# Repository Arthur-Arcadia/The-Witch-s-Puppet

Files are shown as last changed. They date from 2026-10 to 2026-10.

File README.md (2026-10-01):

# The Witch’s Puppet

A cooperative physical computing carnival game exploring haptic communication and information asymmetry.

## Project Documents

- [Project Case Study](the-witchs-puppet-project-case-study.md): concept, inspirations, gameplay, hardware, exhibition evaluation, and reflections.
- [Technical Description - Traps & Punishment](technical-description-traps-and-punishment.md): trap sensing, ESP32 communication, enclosure iterations, code excerpts, and prototype outcomes.
- [Watch the project demonstration](https://www.youtube.com/watch?v=2GjQerEt0JA)

## Image Assets

Keep the `assets/` directory alongside the Markdown files. Images use relative paths and retain the original files extracted from the Word documents.

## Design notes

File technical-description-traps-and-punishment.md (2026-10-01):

# Technical Description - Traps & Punishment

**Author:** Zirui Zhou

[Project case study](the-witchs-puppet-project-case-study.md)

## Project Context and My Role

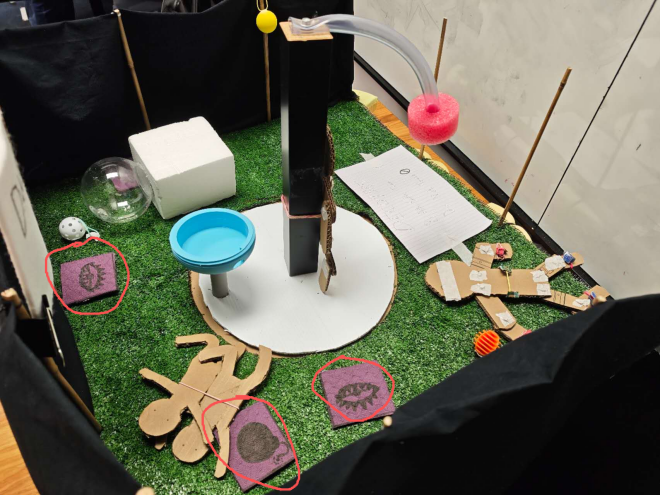
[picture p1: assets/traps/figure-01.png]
Game layout and trap placement


Our group’s project, initially called ‘Dungeon Escape’ and later named ‘The Witch’s Puppet’, where the witch tied in the middle have to control the puppet who is completely blind and deaf to pick up keys and put them into the groove in corresponding order. While the puppet move around, there will be traps that punish the witch if the puppet step onto it.

As the picture illustrated, I am responsible for traps and the punishment structure.

## Design Requirements and Initial Approach

As we expected from the beginning, the trap should be imperceptible, which means the puppet shouldn’t be aware when he/she stepped unto it, so the the witch will be continuously punished until the puppet move away.

SO my idea at first was to make a distance sensitive trap that detects the deformation of the stepping layer when the puppet step onto it. It will have a cover layer for the puppet to step on as well as for the sensor to detect the deformation. Then the problem comes to, how would I be able to hide all those sensors and circuit components below a structure that the puppet will not be noticed? It must be low and smooth enough compare to the normal ground to not let the puppet be noticed.

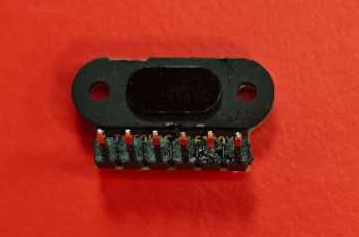
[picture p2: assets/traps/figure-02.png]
Time-of-Flight ranging sensor


This was the first difficulty I had encountered when I’m using the TOF050C, which is called the Time of Flight Laser Ranging Sensor Module.

This sensor sends out a single laser and detects the bouncing time to calculate the range of the object in front of it.

In order to let the player move smother and less annoyed by wires and cables, I decide to use ESP 32 as the board to send out signals remotely, so that a 5v battery is enough to power up a group of trap.

To establish a stable and reusable circuit, I used solder to attach extra footer onto the sensor as well as connecting cables. I also plan to add a LED strip into the system as an indicator for audiences and the witch to know which trap is triggered.

## Success Criteria

As long as the trap detection functions as expected, the puppet will not be awared whether the trap is triggered or not, and the witch and audiences will know which trap is triggered, then it is succeed.

## Initial Structure

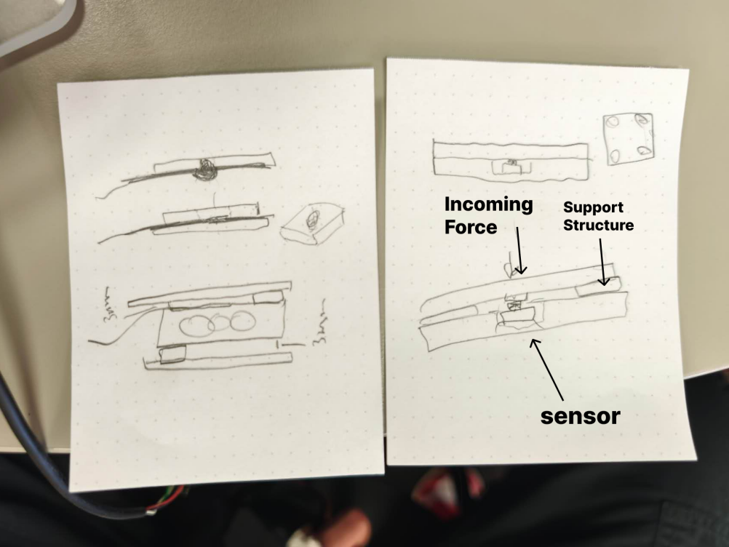
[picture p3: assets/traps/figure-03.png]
Initial trap sensing structure


The accompanying illustration shows the basic idea of how this trap is working, there will be support structure between the top and the bottom layer to allow the top layer to have deformation space. Then the sensor will collect the data. The accompanying circuit image illustrates the electronics; the initial 3D-printed structure is discussed separately.

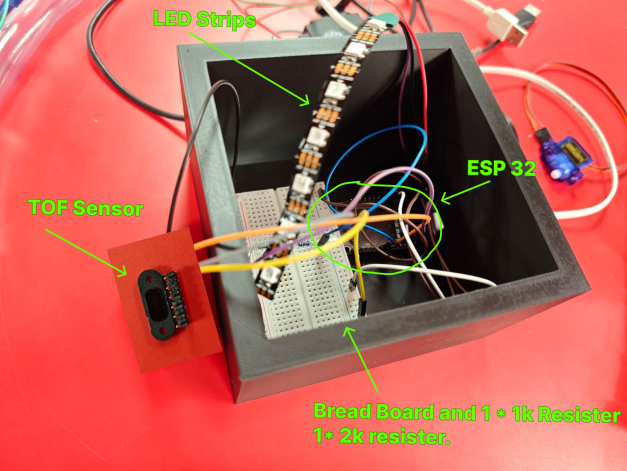
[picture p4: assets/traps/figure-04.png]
Initial trap circuit


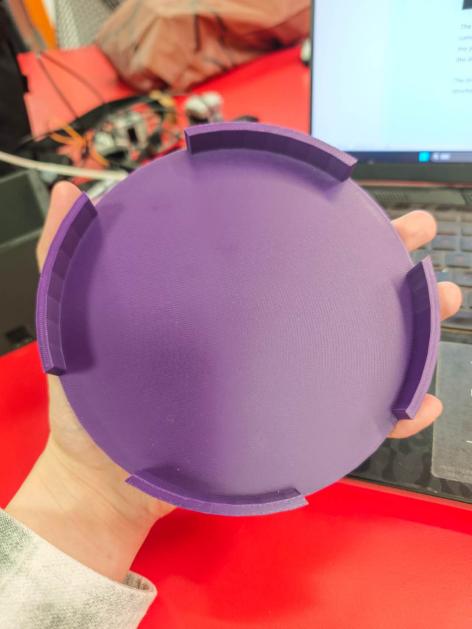
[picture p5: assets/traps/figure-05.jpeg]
Initial circular trap prototype


The circuit react smoothly, so I plan to build a 3D structure to contain the circuit structure. After communication with team mates, we believe the trap shouldn’t be too thick or too high, so that the puppet who can’t see will not be tripped over by the trap. It also have to be big enough to let the deformation happens obvious enough for the sensor to detect.

The initial 3D structure looks like the accompanying prototype, it’s a circle plate with four supporting structures and space to contain circuits. However, it did not fulfill it’s design purpose. It’s a bit too high for puppet to ignore the shape when step onto it, and too low at the same time to not damage the component after covering the circuit on the ground. I.e. if hide all components directly under this plate, the wire would be bent too much to transfer signals.

So this plan was abandoned, as well as the intention to let the puppet step onto the trap. Unless we can raise the ground of the 3\*3m field and place those traps at the same height, otherwise this stepping trick is difficult to be imperceptible.

## Iterations and Fabrication

Fortunately, there’s another sensor called ultrasonic distance sensor that detects wider area of distance compared to the TOF sensor, which means I can place it aside and detects whether the player’s feet is within the certain range.

The puppet no longer need to step onto the trap, it will be triggered as long as the player is closer enough to the trap. The new circuit structure was created, come alone with the 3D printed container. Version 1 looks like below:

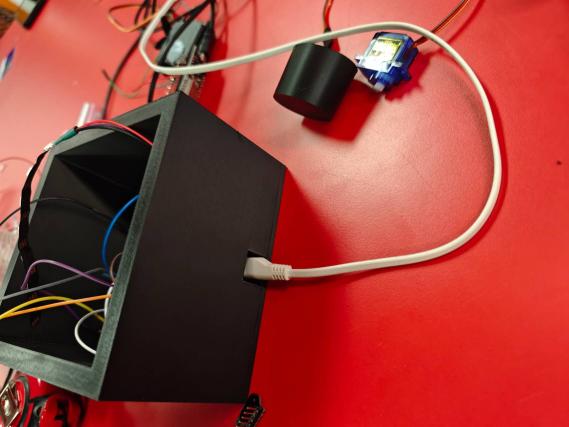
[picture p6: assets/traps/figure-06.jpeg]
Ultrasonic trap prototype


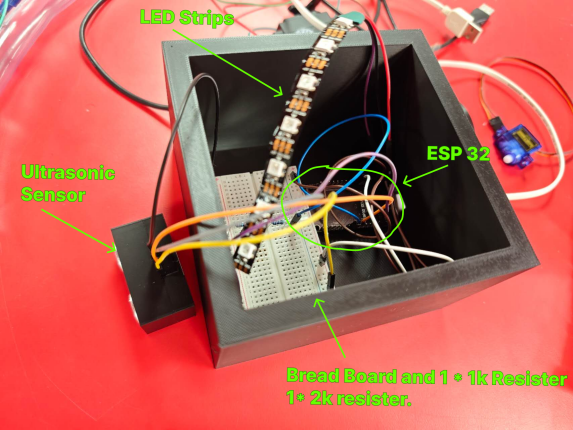
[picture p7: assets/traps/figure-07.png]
Ultrasonic trap circuit


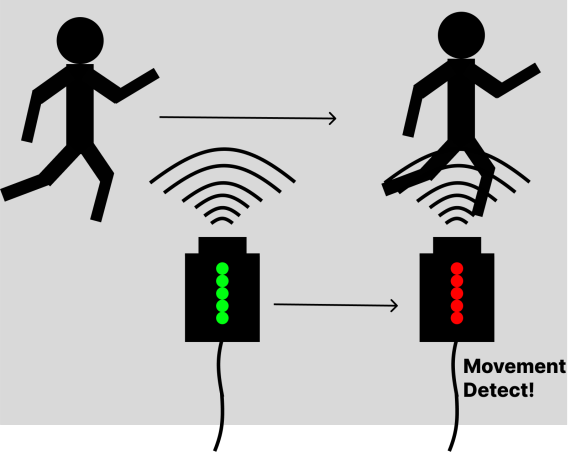
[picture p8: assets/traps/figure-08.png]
First enclosure design


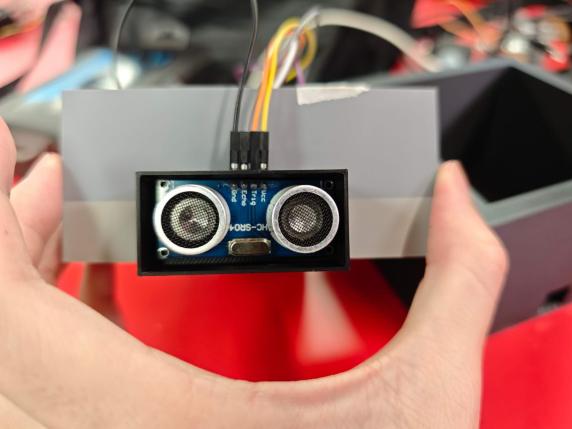
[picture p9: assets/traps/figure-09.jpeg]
Assembled trap enclosure


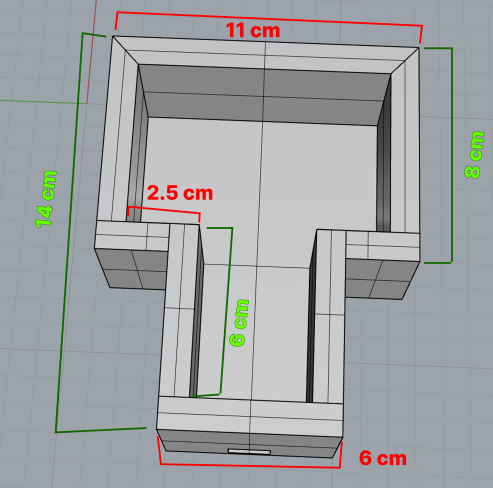
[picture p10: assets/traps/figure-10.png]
Revised enclosure with fitted component compartments


As the photo illustrated above, I have designed a container to put the circuit in, so that it will not be damaged easily if the player accidentally kicked or stepped onto it. However, the box for version 1 seems too large to safely contain all the components without worrying the displacement when experiencing shaking and rolling. So after measuring the specific length of each component, version 2 was designed as shown in the accompanying illustration. The wider area is for the bread board, and the thinner and longer area is for ESP 32 Board. Version 2 successfully limited the movement of each component and maintained the position of every cables.

## Microcontroller Selection and Wireless Communication

The purpose of the trap is to activate the ‘punishment machine’ hangs at the top of the witch, since these traps will be randomly located for each new round, cables and wires is the biggest limitation that might affect puppet’s movement. So our group decides to use remote communication, which comes to the ESP 32, the micro-controller integrated with Wi-Fi and Bluetooth communication.

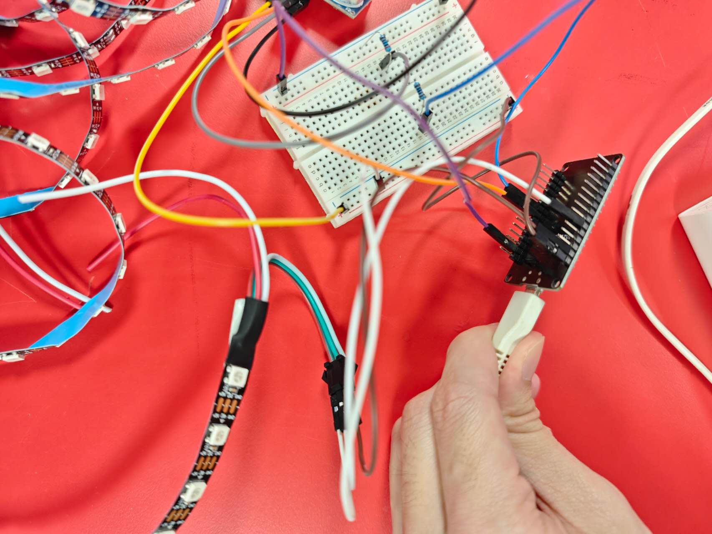
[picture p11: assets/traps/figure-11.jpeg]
ESP32 hardware


This micro-controller allows remote data transmission with 5v and 3.3v power outlet, and up to 30 pins (includes power) for components. However, the operating current is lower than Arduino UNO (about 500mA), so extra power supply is needed to drive components like motor.

Since the data is sent by the trap and received by the punishment system, 2 esp32 is needed to communicate between each other.

As the research and AI suggested, a communication method called ‘ESP NOW’ is highly recommended by sending the data through ESP32’s Wi-Fi module directly to another ESP32 with corresponding MAC address without using actual WLAN.

So the whole system was developed based on 2 separate codes, correspondingly responsible for sending and receiving. More specifically, the sending code receives data from ultrasonic distance sensor, and sends out through ESP-NOW, while triggers color changing of LED strip. On the other side, another ESP 32 receives the data and trigger the servo if the trap was triggered.

The following images show excerpts of the sending and receiving code.

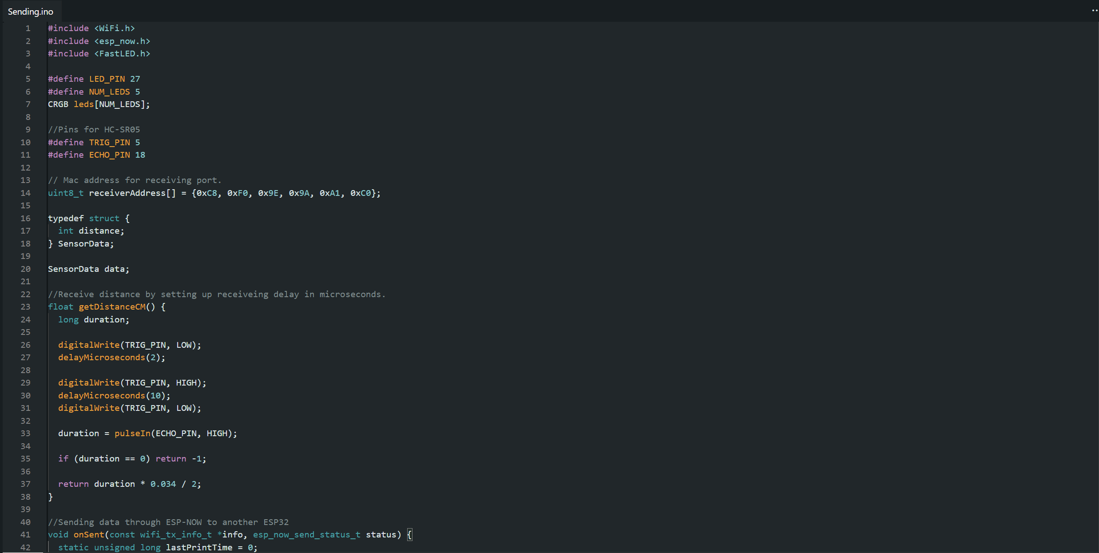
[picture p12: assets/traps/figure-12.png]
Sender code excerpt


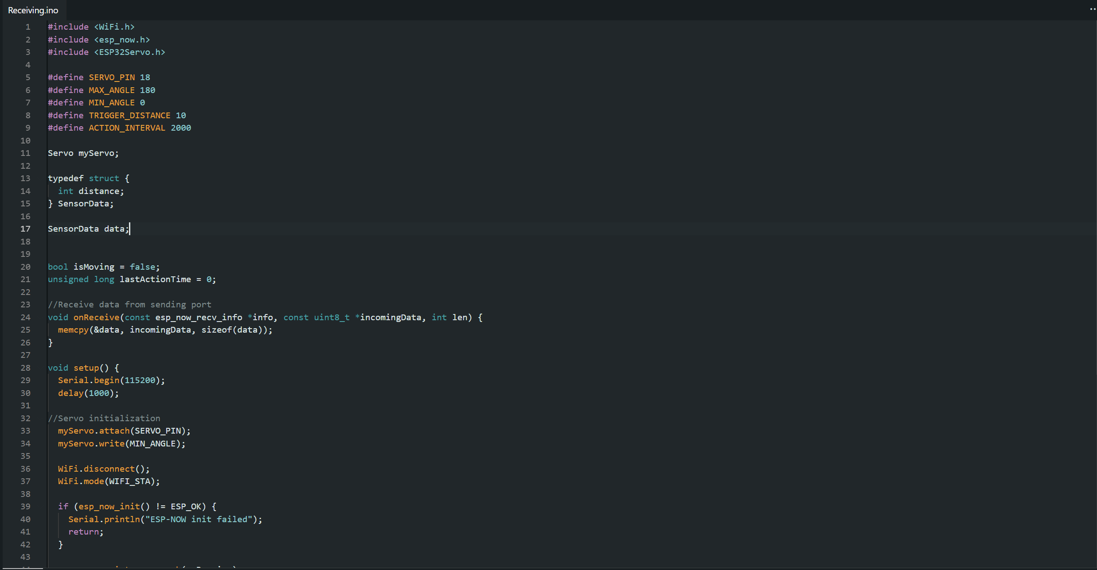
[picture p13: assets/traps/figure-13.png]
Receiver code excerpt


## Limitations and Next Iteration

Since this ‘pass through detecting’ trap is a bit large in volume, a kicking or treading could seriously damage and affect the current circuit, even under the protection of 3D printed shell. And a bread board is used with unsturdy cable connection for this ‘Tech Spike’. The next iteration will focus on reducing its volume and reinforce the stability of the circuit.

## Prototype Outcome

The answer is yes for the current period. The trap can be triggered accurately and rapidly, the delay of data transmission between two ESP32 is within acceptable range, so I believe my design has achieved its design purpose.

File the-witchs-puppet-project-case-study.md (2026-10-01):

# The Witch’s Puppet — Project Case Study

**Author:** Zirui Zhou  
**Institution:** University of Queensland

[Technical Description - Traps & Punishment](technical-description-traps-and-punishment.md) · [Project demonstration](https://www.youtube.com/watch?v=2GjQerEt0JA)

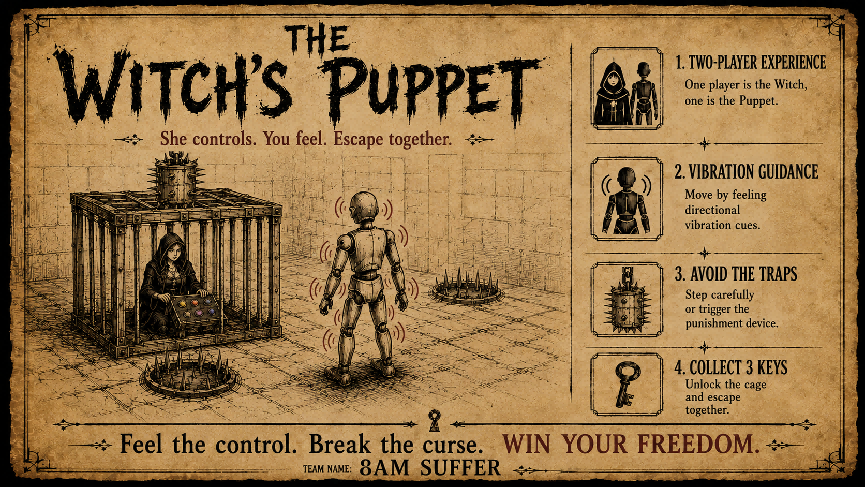
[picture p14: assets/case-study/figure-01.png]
The Witch’s Puppet project poster


*Figure 1: Poster for The Witch’s Puppet.*

## Project Overview

Traditional carnival games usually provide players with visual appeal, extreme emotional feedback, and a sense of achievement by using lights, sounds, and interactions. They test players’ strength, speed, accuracy, and reactions by setting up simple rules and different levels of challenges, bringing happiness and an unforgettable experience to both players and spectators. What will carnival games look like in the future?

This paper presents an interactive prototype project that explores a alternative theme to traditional competitive carnival games: cooperation. In this game, two players act separately as the witch and the puppet. The goal is simple: the witch has to control the movement of the puppet (who is blind and deaf) through a panel, and the puppet has to follow the commands to move around the field, collecting keys while avoiding traps.

This project shows our understanding of and attempts toward future carnival games. It will also show how this game creates cooperative experiences through restricted, asymmetrical communication, and physical interaction.

## Research Areas

- **Human-centered computing** → Interaction Design → Interaction design process and method

- **Hardware** → Sensor devices and platforms

## Keywords

Interaction Design, Carnival Games, Physical Interactive Experience, Haptic Communication, Remote Data Transmission through Electrical Components

## Introduction

From remote communication to virtual reality, the forms of interaction that humans can experience have been constantly changing with the development of technology. The same goes for carnival games. From the baseball toss, balls-in-the-bucket, and ring toss seen in old carnival photos [2], to Whac-A-Mole, Dance Dance Revolution, Laser Maze, and VR shooting games, the evolution of technology has enriched the ways users can interact with games. It can be expected that technology will play a larger role in future carnival games, creating more immersive and realistic experiences for players and offering developers more design opportunities and creative expressions.

Inspired by marionettes and dungeon escape rooms, Witch’s Puppet combines both puppet manipulation and escape elements to provide a unique experience for players. Similar to a marionette show, the witch needs to control the movement of the puppet, while the puppet has to avoid traps and collect keys hanging in random locations, ultimately saving the witch from the cage.

This project aims to explore the relationship between technology and interaction, as well as define a possible theme for future carnival games. Specifically, technology uniquely shapes the gameplay experience by challenging players to maintain remote communication within a restricted environment.

## Related Work and Inspirations

The inspiration for this project came from various aspects. The way of communication between the witch and the puppet imitates the manipulation of the traditional ‘Marionette’, where strings are attached all around the puppet’s body to enable sensitive movement control [4].

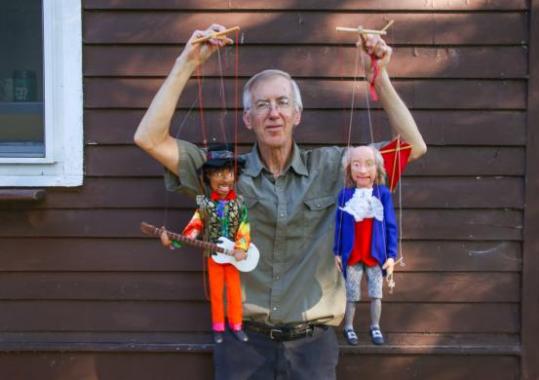
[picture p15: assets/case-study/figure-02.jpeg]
Marionette inspiration


*Figure 2: A puppeteer is showing his puppets*

Instead of using strings and ropes, this project integrates electronic components and wearable haptics to maintain communication between the witch and the puppet, solving both distance and stability problems for remote control. The concepts of the cage, traps, and the rescue mechanism came from the game ‘Dungeon Escape’, where the player needs to get keys while avoiding traps and monsters, ultimately escaping from the dungeon [1]. 

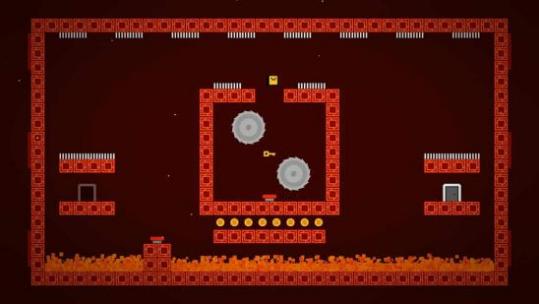
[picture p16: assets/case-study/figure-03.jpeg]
Dungeon Escape inspiration


*Figure 3: The game ‘Dungeon Escape’*

However, instead of punishing the puppet who triggers the trap, the punishment system—which is remotely connected to the traps—will punish the witch who controls the puppet. This means the witch has to bear the consequences for leading the puppet into a trap.

In addition, this game grounds the witch and deprives the puppet of sight and hearing, so that the witch can only give commands, and the puppet can only follow them without knowing the exact situation. This idea was extracted and combined from the games ‘It Takes Two’ and ‘Keep Talking and Nobody Explodes’.

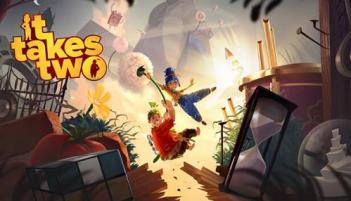
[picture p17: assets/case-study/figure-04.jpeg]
It Takes Two inspiration


*Figure 4: It Takes Two.*

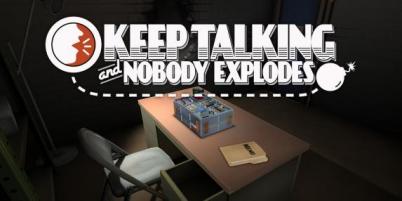
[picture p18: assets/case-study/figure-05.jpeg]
Keep Talking and Nobody Explodes inspiration


*Figure 5: Keep Talking and Nobody Explodes.*

While both games emphasize cooperation between players, ‘It Takes Two’ focuses more on collaboration to solve puzzles and difficulties together [5], whereas ‘Keep Talking...’ highlights the information asymmetry between players [3]. Therefore, Witch’s Puppet extracts the idea of ‘cooperation’ while maintaining ‘information asymmetry’ to form a completely different experience between the witch and the puppet.

## Design and Implementation

Considering the player experience and difficulty level, this game removes the time limit to ensure that every pair of players can finish the game. Players are allowed to have a conversation before the start of the game to discuss any strategy. With three keys in total, the puppet can only carry one key at a time until it is placed into the correct slot. While this game focuses mainly on communication and punishment, the gameplay flow is relatively simple.

1. Discuss strategy.
2. Test the vibration mappings.
3. Navigate the space and avoid traps.
4. Collect and place the keys.
5. Unlock the cage.

### Technical Detail

The core component of this project is the esp-32 Module, it ensures the remote communication while prevent the puppet from tripping over the circuits when moving around. 11 ESP-32 S3 Zero and 1 ESP-32 Devkit v1 were used for the final iteration, 4 on the traps, 1 on the punishment system, 1 for the controller, and 6 for the wearable set.

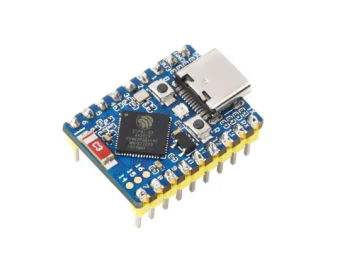
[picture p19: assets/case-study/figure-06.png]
ESP32 S3 Zero


*Figure 6: ESP32 S3 Zero.*

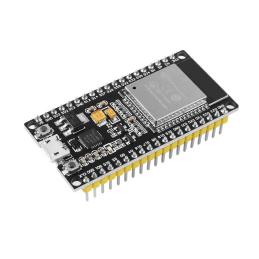
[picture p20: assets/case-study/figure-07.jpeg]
ESP32 Devkit V1


*Figure 7: ESP32 Devkit V1.*

Six 5V mini vibration motors are deployed on the wearable set, with each connected to an ESP-32 S3 Zero.

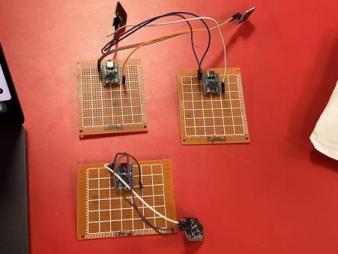
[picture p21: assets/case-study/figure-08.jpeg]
Wearable vibration motor and ESP32 assembly


*Figure 8: Vibration motor and ESP32 assembly.*

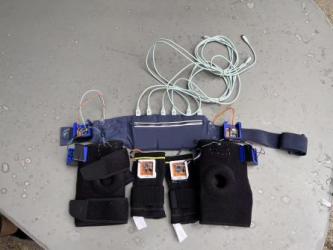
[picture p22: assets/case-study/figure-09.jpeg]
Complete wearable haptic system


*Figure 9: Complete wearable haptic system.*

The controller is composed of 6 buttons and 1 ESP-32, each button sends signals through a specific MAC address corresponding to the unique esp-32 attached to puppet’s body.

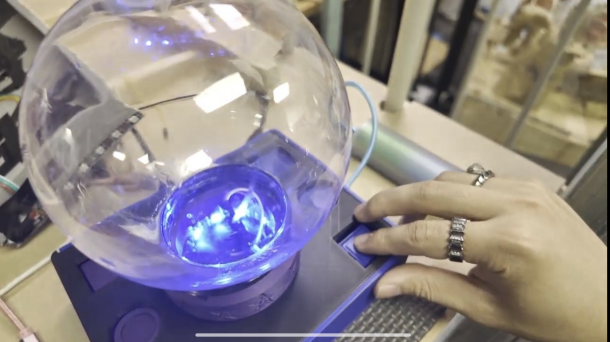
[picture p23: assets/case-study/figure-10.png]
Six-button controller


*Figure 10: Controller Display*

For the traps, each is composed of 1 esp32 and 1 ultrasonic sensor. The ultrasonic sensor emits ultrasonic waves forward and returns the distance of the closest object within a fan-shaped area.

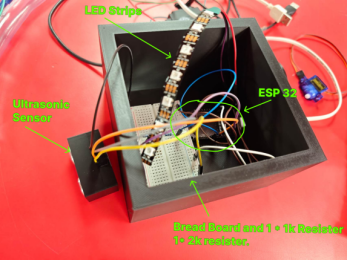
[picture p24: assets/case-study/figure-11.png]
Ultrasonic trap structure


*Figure 11: Trap structure.*

Ultrasonic detection illustration

*Figure 12: Ultrasonic sensing illustration.*

A 360-degree 20kg motor is used to drive the punishment system to move back and forth repeatedly whenever any trap is triggered. An ESP32 is connected to the motor to receive signals from the traps.

3 Hall sensors are attached under each of the key slots to detect magnets under each key.

Arduino Uno and Hall sensors

*Figure 13: Arduino Uno and three Hall sensors.*

Keys and matching key slots

*Figure 14: Keys and matching key slots.*

If all keys are placed in the correct slots, a 12kg servo motor will raise the lock bolt and release the witch.

The ESP32 modules communicate through the ‘ESP-NOW’ protocol. It is the most appropriate method according to the demands of low latency, multiple ESP32 module transitions, and separate power supplies.

### Technical Walk-through

Integrating the technical detail into the walk-through:

1. The witch press buttons on the controller, sending signals through different MAC address to related ESP-32 attached around puppet’s body.
2. Puppet move his limb according to the vibration triggered by the vibration motor.
3. The ultrasonic sensor scans the space at its front, returning signals when the object is within the certain range. Once the indicating LED light turns into green, the trap is then triggered, data sent through ESP-32.
4. The ESP-32 for the punishment system receives the command of ‘triggered’, then the motor start to rotate back and forth 1 round per 2 seconds.
5. The puppet grabs the hanging key under the guidance.
6. The puppet put the key into the correct slot, the magnet under the key triggers the hall sensor, indicator LED turns on.
7. After all the keys are placed in the correct slot, the LED light around the key slot will flick, and the 12kg motor will be triggered to unlock the cage.

## Experiential Contributions

This project explores three concepts from different aspects in terms of information acquisition and utilization, communication under a restricted environment, and the theme for future carnival games.

### Asymmetric Information Experience

The ‘Witch’s Puppet’ emphasizes imbalanced information collection and operation. The witch can only see the situation on the game field, including the locations of traps and keys, but she cannot move around by herself to directly utilize the information she has acquired. The puppet can move around and make direct contact with the environment; however, it cannot acquire direct visual or auditory information, and its movement depends fully on the vibrations sent by the witch. This unequal information acquisition and application is one of the main experiential contributions of this project.

### Communication Under Restricted Environment

Another contribution of this project follows the information collection stage. How can we maintain the information transmission between two ‘sensory-deprived’ players when the primary methods of communication used by humans are prohibited? The solution from Witch’s Puppet introduces ‘haptic communication’ by implementing a remote vibration system to maintain communication under a restricted environment. This solution is proposed based on the information loss occurring during the transmission from the witch’s visual signals to the puppet’s haptic sensations. This experience holds significant promise for exploring haptic information exchange when conventional communication is restricted in emergencies or special environments.

### Re-imagine the Carnival Experience

Traditional carnival games primarily challenge players through competition, such as comparing scores or completion times [6]. In contrast, this work explores a novel concept: encouraging cooperation under system-imposed restrictions, emphasizing the shift in the relationship between players from competitors to collaborators while preserving the fun of carnival games.

## Exhibition Evaluation

This game was tested by different user groups during the exhibition, from middle school students to the elderly, where various performances were collected and analyzed in three aspects: communication, cooperation, and completion.

### Communication

According to the recordings, most of the teams established relatively clear communication at the initial stage of the game. Witches tended to map the button layout to the puppet, then performed actions according to the puppet's motion patterns. Puppets showed various moving patterns in response to the vibration. A single group of players failed to build a clear communication protocol, which took them a considerable amount of time to complete the game. This was due to the thick clothing the puppet wore, which blocked the vibration sensation. The overall feedback proves the possibility of establishing simple communication through vibration alone.

### Cooperation

Observations showed that after establishing a basic communication protocol, the puppet and witch roles began collaborating, typically by adapting to each other's behavioral patterns. All groups attempted collaboration once they understood the rules; no participants insisted on playing independently. Post-game feedback revealed no negative comments regarding the game's enjoyment. These results demonstrate that a cooperative theme, rather than competition, can successfully deliver an engaging and memorable experience for both players and spectators in a carnival game context.

### Completion

Most of the groups finished the game within 10 minutes, indicating a relatively successful design in terms of game difficulty and process duration. Our analysis indicates that groups with longer completion times typically faced one or more of the following issues: unclear communication protocols, attenuated vibration sensation due to thick clothing, misunderstanding of game objectives, or misinterpretation of the vibration signals.

## Reflections

Through the development and user testing of this interactive game, three main insights were gained. First, when communication is restricted, players attempt to develop new protocols from limited information through iterative practice. This is shown in their attempts to figure out specific button mappings and construct a shared protocol. Second, while exploring new communication modalities, players build trust through interaction. This manifests in the 'puppet' role (who lacks visual and auditory cues) consistently following the 'witch's' signals, demonstrating unconditional trust. Finally, a complex circuit and technical structure is not a prerequisite for an excellent game. When the core concept is sufficiently novel and engaging, technology serves primarily as a supportive tool to make the gameplay smoother and easier to implement.

## Conclusion

To explore the future direction of carnival games, the '8 AM Suffer Team' developed *Witch's Puppet*, focusing on collaboration under communication constraints and information asymmetry. The system was built using a low-delay, low-failure-rate, and highly replicable hardware architecture. Through user testing and feedback collection during the final exhibition, along with the resulting award recognition, the team validated the significant potential of collaborative themes in future carnival games. This approach successfully delivers an engaging spectator experience without compromising fun and challenge.

## References

[1] Dungeon Escape for Nintendo Switch - Nintendo Official Site: *https://www.nintendo.com/us/store/products/dungeon-escape-switch/*. Accessed: 2026-06-13.

[2] genavieveblackwood 2023. Carnivals and Freaks: A History. *Genavieve Blackwood’s Author Website*.

[3] Keep Talking and Nobody Explodes - Defuse a bomb with your friends.: *https://keeptalkinggame.com/*. Accessed: 2026-06-13.

[4] Marionette \| Puppetry, Strings, Manipulation \| Britannica: *https://www.britannica.com/art/marionette*. Accessed: 2026-06-13.

[5] Racoti, A. 2023. Review: It Takes Two. *Gaming and God*.

[6] 2025. Carnival Game Ideas for School Fairs and Carnivals - Perfect Parties USA \| Perfect Parties USA.

## Use of Generative AI

This report uses ChatGPT 4.0 and Gemini 3.5 for grammar check and assignment brief explanation only.

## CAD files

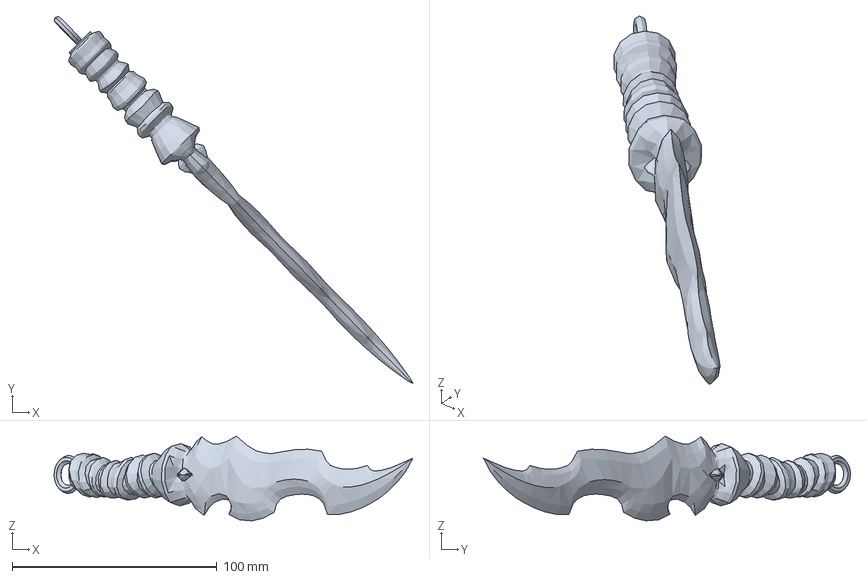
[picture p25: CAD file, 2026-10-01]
Model/Dagger_Test.3mf
175.3 x 179.3 x 41.4 mm

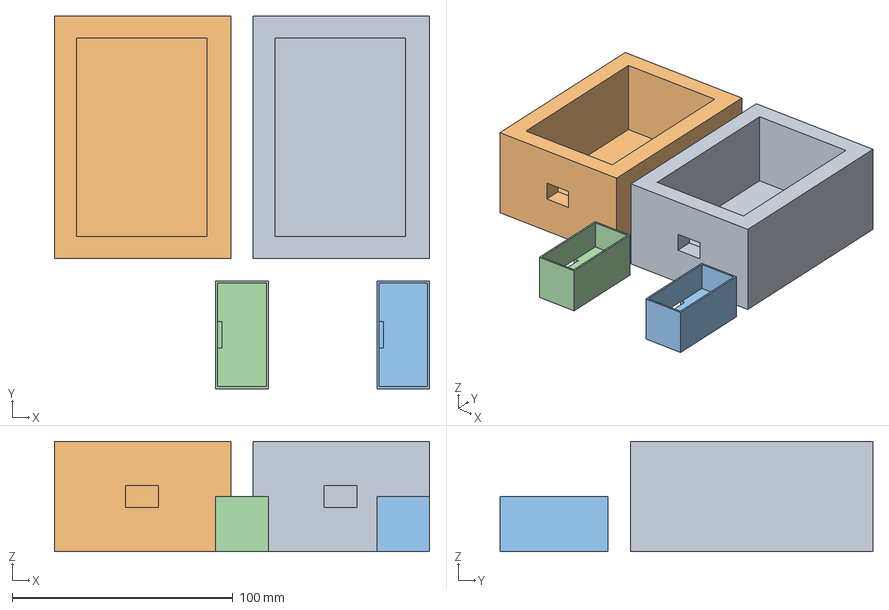
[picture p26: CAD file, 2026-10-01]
Model/Container.3mf
170.0 x 169.0 x 50.0 mm

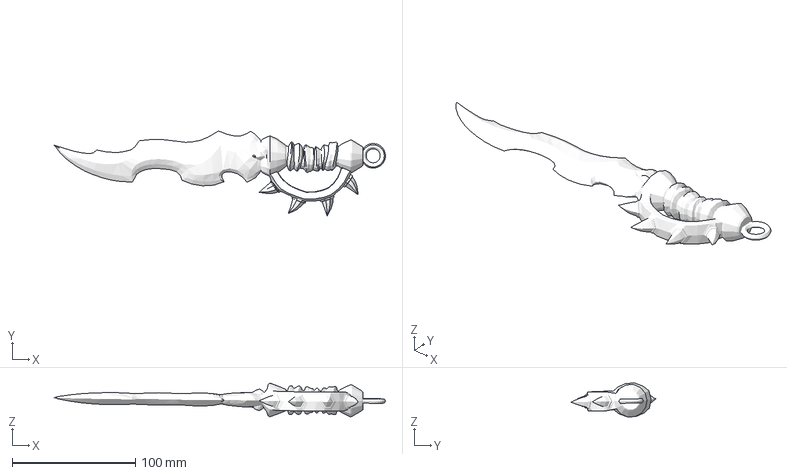
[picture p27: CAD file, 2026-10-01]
Model/Dagger.3mf
268.6 x 69.0 x 27.4 mm

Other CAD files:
Model/Container.3dm
Model/Container.stl
Model/Container_V2.3dm
Model/Dagger.3dm

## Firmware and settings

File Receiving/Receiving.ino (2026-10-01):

#include <WiFi.h>
#include <esp_now.h>
#include <ESP32Servo.h>

#define SERVO_PIN 18
#define TOP_DISTANCE 80
#define BOTTOM_DISTANCE 50
#define ACTION_INTERVAL 1000 

Servo myServo;

typedef struct {
  int distance;
  uint8_t sensorID; 
} SensorData;

int distances[4] = {999, 999, 999, 999};                 // [UPDATED]
unsigned long lastSeen[4] = {0, 0, 0, 0};  

bool isMoving = false;
unsigned long lastActionTime = 0; 

//Receive data from sending port
void onReceive(const esp_now_recv_info *info, const uint8_t *incomingData, int len) {
  SensorData incoming;   // [UPDATED]
  memcpy(&incoming, incomingData, sizeof(incoming));   // [UPDATED]

  // [UPDATED] Validate sensor ID before storing
  if (incoming.sensorID >= 1 && incoming.sensorID <= 4) {
    int index = incoming.sensorID - 1;   // [UPDATED]

    distances[index] = incoming.distance;   // [UPDATED]
    lastSeen[index] = millis();            // [UPDATED]

    // [UPDATED] Debug print
    Serial.print("Sensor ");
    Serial.print(incoming.sensorID);
    Serial.print(": ");
    Serial.print(incoming.distance);
    Serial.println(" cm");
  }
}

void setup() {
  Serial.begin(115200);
  delay(1000);

//Servo initialization
  myServo.attach(SERVO_PIN, 500, 2500);
  myServo.write(0);

  WiFi.disconnect();
  WiFi.mode(WIFI_STA);

  Serial.print("Receiver MAC: ");   // [UPDATED]
  Serial.println(WiFi.macAddress());

  if (esp_now_init() != ESP_OK) {
    Serial.println("ESP-NOW init failed");
    return;
  }

  esp_now_register_recv_cb(onReceive);
}

void loop() {
  unsigned long now = millis();

  // [UPDATED] Timeout check for offline sensors
  for (int i = 0; i < 4; i++) {
    if (now - lastSeen[i] > 1000) {   // [UPDATED]
      distances[i] = 999;            // [UPDATED]
    }
  }

  // [UPDATED] Check all 4 sensors
  // Trigger if ANY sensor is close enough
  bool triggered = false;   // [UPDATED]

  for (int i = 0; i < 4; i++) {
    if (distances[i] < TOP_DISTANCE && distances[i] > BOTTOM_DISTANCE) {   // [UPDATED]
      triggered = true;                      // [UPDATED]
      break;
    }
  }

//Determines when to move
  if (triggered) {   // [UPDATED]
    if (!isMoving && now - lastActionTime > ACTION_INTERVAL) {
      isMoving = true;
      lastActionTime = now;
    }
  }

  if (isMoving) {
    Serial.println("Servo Triggered");   // [UPDATED]

    myServo.write(150);   // fast forward strike
    delay(720);           // swing out (~180°+)

    myServo.write(90);    // stop briefly
    delay(80);

    myServo.write(30);    // fast reverse reset
    delay(740);           // return to start

    myServo.write(90);    // stop

    isMoving = false;
    lastActionTime = millis();
  }
}

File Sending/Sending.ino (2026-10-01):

#include <WiFi.h>
#include <esp_now.h>
#include <FastLED.h>

// =========================
// ESP32-S3-Zero Pin Config
// =========================
#define LED_PIN 21          // Onboard WS2812 RGB LED on ESP32-S3-Zero
#define NUM_LEDS 1          // Only 1 onboard RGB LED

#define TRIG_PIN 5
#define ECHO_PIN 6

#define SENSOR_ID 3 // Different on each ESP32

CRGB leds[NUM_LEDS];

// Receiver MAC address
uint8_t receiverAddress[] = {0xC8, 0xF0, 0x9E, 0x9B, 0x6A, 0x1C};
//c8:f0:9e:9b:6a:1c

typedef struct {
  int distance;
  uint8_t sensorID;
} SensorData;

SensorData data;

// =========================
// Ultrasonic Distance Read
// =========================
float getDistanceCM() {
  long duration;

  digitalWrite(TRIG_PIN, LOW);
  delayMicroseconds(2);

  digitalWrite(TRIG_PIN, HIGH);
  delayMicroseconds(10);
  digitalWrite(TRIG_PIN, LOW);

  duration = pulseIn(ECHO_PIN, HIGH, 30000);  // timeout 30ms

  if (duration == 0) return -1;

  return duration * 0.034 / 2;
}

// =========================
// ESP-NOW Send Callback
// =========================
void onSent(const wifi_tx_info_t *info, esp_now_send_status_t status) {
  // Optional debug
  // Serial.println(status == ESP_NOW_SEND_SUCCESS ? "Success" : "Fail");
}

void setup() {
  Serial.begin(115200);
  delay(1000);

  Serial.println("BOOTING...");

  // =========================
  // LED Init
  // =========================
  FastLED.addLeds<WS2812, LED_PIN, GRB>(leds, NUM_LEDS);
  FastLED.setBrightness(50);
  FastLED.clear();
  FastLED.show();   // LED off at boot

  // =========================
  // Ultrasonic Init
  // =========================
  pinMode(TRIG_PIN, OUTPUT);
  pinMode(ECHO_PIN, INPUT);

  Serial.println("Ultrasonic Sensor OK");

  // =========================
  // ESP-NOW Init
  // =========================
  WiFi.disconnect();
  WiFi.mode(WIFI_STA);

  if (esp_now_init() != ESP_OK) {
    Serial.println("ESP-NOW init failed");
    return;
  }

  Serial.println("ESP-NOW OK");

  esp_now_register_send_cb(onSent);

  esp_now_peer_info_t peerInfo = {};
  memcpy(peerInfo.peer_addr, receiverAddress, 6);
  peerInfo.channel = 0;
  peerInfo.encrypt = false;

  if (esp_now_add_peer(&peerInfo) != ESP_OK) {
    Serial.println("Failed to add peer");
    return;
  }

  Serial.println("Sender ready");
}

void loop() {
  float distance = getDistanceCM();

  if (distance > 0) {

    // =========================
    // In Trigger Range
    // =========================
    if (distance > 50 && distance < 80) {

      // LED ON
      leds[0] = CRGB::Red;
      FastLED.show();

      // Prepare data
      data.distance = (int)distance;
      data.sensorID = SENSOR_ID;

      // Send ONLY when triggered
      esp_now_send(receiverAddress, (uint8_t *)&data, sizeof(data));

      // Serial Output
      Serial.print("Sensor ");
      Serial.print(SENSOR_ID);
      Serial.print("; Distance: ");
      Serial.print(distance);
      Serial.println(" cm -> triggered");

    } else {

      // =========================
      // Out of Trigger Range
      // =========================

      // LED OFF
      leds[0] = CRGB::Black;
      FastLED.show();

      // Serial Output ONLY
      Serial.print("Sensor ");
      Serial.print(SENSOR_ID);
      Serial.print("; Distance: ");
      Serial.print(distance);
      Serial.println(" cm");
    }

  } else {

    // No reading
    leds[0] = CRGB::Black;
    FastLED.show();

    Serial.print("Sensor ");
    Serial.print(SENSOR_ID);
    Serial.println("; Out of range");
  }

  delay(260 + random(0, 80));
}
